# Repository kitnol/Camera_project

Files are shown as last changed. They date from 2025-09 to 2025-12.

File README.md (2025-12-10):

| Supported Targets | ESP32-S3 |
| --- | --- |

# Basic Console Example (`esp_console_repl`)

(See the README.md file in the upper level 'examples' directory for more information about examples.)

This example illustrates the usage of the REPL (Read-Eval-Print Loop) APIs of the [Console Component](https://docs.espressif.com/projects/esp-idf/en/latest/esp32/api-reference/system/console.html#console) to create an interactive shell on the ESP chip. The interactive shell running on the ESP chip can then be controlled/interacted with over a serial interface. This example supports UART and USB interfaces.

The interactive shell implemented in this example contains a wide variety of commands, and can act as a basis for applications that require a command-line interface (CLI).

Compared to the [advanced console example](../advanced), this example requires less code to initialize and run the console. `esp_console_repl` API handles most of the details. If you'd like to customize the way console works (for example, process console commands in an existing task), please check the advanced console example.

## How to use example

This example can be used on boards with UART and USB interfaces. The sections below explain how to set up the board and configure the example.

### Using with UART

When UART interface is used, this example should run on any commonly available Espressif development board. UART interface is enabled by default (`CONFIG_ESP_CONSOLE_UART_DEFAULT` option in menuconfig). No extra configuration is required.

### Using with USB_SERIAL_JTAG

*NOTE: We recommend to disable the secondary console output on chips with USB_SERIAL_JTAG since the secondary serial is output-only and would not be very useful when using a console application. This is why the secondary console output is deactivated per default (CONFIG_ESP_CONSOLE_SECONDARY_NONE=y)*

On chips with USB_SERIAL_JTAG peripheral, console example can be used over the USB serial port.

* First, connect the USB cable to the USB_SERIAL_JTAG interface.
* Second, run `idf.py menuconfig` and enable `CONFIG_ESP_CONSOLE_USB_SERIAL_JTAG` option.

For more details about connecting and configuring USB_SERIAL_JTAG (including pin numbers), see the IDF Programming Guide:
* [ESP32-C3 USB_SERIAL_JTAG](https://docs.espressif.com/projects/esp-idf/en/stable/esp32c3/api-guides/usb-serial-jtag-console.html)
* [ESP32-S3 USB_SERIAL_JTAG](https://docs.espressif.com/projects/esp-idf/en/stable/esp32s3/api-guides/usb-serial-jtag-console.html)

### Using with USB CDC (USB_OTG peripheral)

USB_OTG peripheral can also provide a USB serial port which works with this example.

* First, connect the USB cable to the USB_OTG peripheral interface.
* Second, run `idf.py menuconfig` and enable `CONFIG_ESP_CONSOLE_USB_CDC` option.

For more details about connecting and configuring USB_OTG (including pin numbers), see the IDF Programming Guide:
* [ESP32-S2 USB_OTG](https://docs.espressif.com/projects/esp-idf/en/stable/esp32s2/api-guides/usb-otg-console.html)
* [ESP32-S3 USB_OTG](https://docs.espressif.com/projects/esp-idf/en/stable/esp32s3/api-guides/usb-otg-console.html)

### Other configuration options

This example has an option to store the command history in Flash. This option is enabled by default.

To disable this, run `idf.py menuconfig` and disable `CONFIG_CONSOLE_STORE_HISTORY` option.

### Build and Flash

Build the project and flash it to the board, then run monitor tool to view serial output:

```
idf.py -p PORT flash monitor
```

(Replace PORT with the name of the serial port to use.)

(To exit the serial monitor, type ``Ctrl-]``.)

See the Getting Started Guide for full steps to configure and use ESP-IDF to build projects.

## Example Output

Enter the `help` command get a full list of all available commands. The following is a sample session of the Console Example where a variety of commands provided by the Console Example are used.

On ESP32, GPIO15 may be connected to GND to remove the boot log output.

```
This is an example of ESP-IDF console component.
Type 'help' to get the list of commands.
Use UP/DOWN arrows to navigate through command history.
Press TAB when typing command name to auto-complete.
[esp32]> help
help
  Print the list of registered commands

free
  Get the total size of heap memory available

restart
  Restart the program

deep_sleep  [-t <t>] [--io=<n>] [--io_level=<0|1>]
  Enter deep sleep mode. Two wakeup modes are supported: timer and GPIO. If no
  wakeup option is specified, will sleep indefinitely.
  -t, --time=<t>  Wake up time, ms
      --io=<n>  If specified, wakeup using GPIO with given number
  --io_level=<0|1>  GPIO level to trigger wakeup

join  [--timeout=<t>] <ssid> [<pass>]
  Join WiFi AP as a station
  --timeout=<t>  Connection timeout, ms
        <ssid>  SSID of AP
        <pass>  PSK of AP

[esp32]> free
257200
[esp32]> deep_sleep -t 1000
I (146929) deep_sleep: Enabling timer wakeup, timeout=1000000us
I (619) heap_init: Initializing. RAM available for dynamic allocation:
I (620) heap_init: At 3FFAE2A0 len 00001D60 (7 KiB): DRAM
I (626) heap_init: At 3FFB7EA0 len 00028160 (160 KiB): DRAM
I (645) heap_init: At 3FFE0440 len 00003BC0 (14 KiB): D/IRAM
I (664) heap_init: At 3FFE4350 len 0001BCB0 (111 KiB): D/IRAM
I (684) heap_init: At 40093EA8 len 0000C158 (48 KiB): IRAM

This is an example of ESP-IDF console component.
Type 'help' to get the list of commands.
Use UP/DOWN arrows to navigate through command history.
Press TAB when typing command name to auto-complete.
[esp32]> join --timeout 10000 test_ap test_password
I (182639) connect: Connecting to 'test_ap'
I (184619) connect: Connected
[esp32]> free
212328
[esp32]> restart
I (205639) restart: Restarting
I (616) heap_init: Initializing. RAM available for dynamic allocation:
I (617) heap_init: At 3FFAE2A0 len 00001D60 (7 KiB): DRAM
I (623) heap_init: At 3FFB7EA0 len 00028160 (160 KiB): DRAM
I (642) heap_init: At 3FFE0440 len 00003BC0 (14 KiB): D/IRAM
I (661) heap_init: At 3FFE4350 len 0001BCB0 (111 KiB): D/IRAM
I (681) heap_init: At 40093EA8 len 0000C158 (48 KiB): IRAM

This is an example of ESP-IDF console component.
Type 'help' to get the list of commands.
Use UP/DOWN arrows to navigate through command history.
Press TAB when typing command name to auto-complete.
[esp32]>

```

## Troubleshooting

### Line Endings

The line endings in the Console Example are configured to match particular serial monitors. Therefore, if the following log output appears, consider using a different serial monitor (e.g. Putty for Windows) or modify the example's [UART configuration](#Configuring-UART-and-VFS).

```
This is an example of ESP-IDF console component.
Type 'help' to get the list of commands.
Use UP/DOWN arrows to navigate through command history.
Press TAB when typing command name to auto-complete.
Your terminal application does not support escape sequences.
Line editing and history features are disabled.
On Windows, try using Putty instead.
esp32>
```

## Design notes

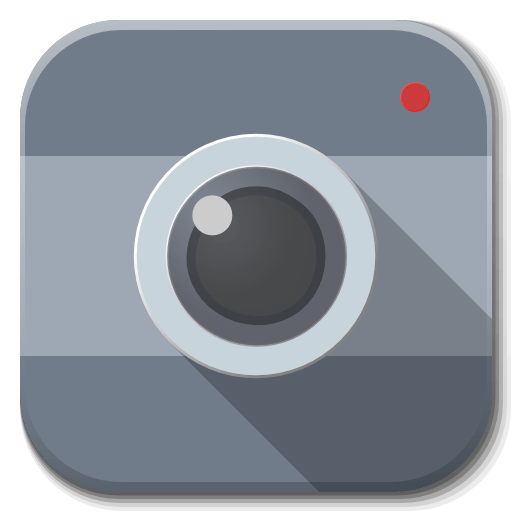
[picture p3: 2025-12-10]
App/Camera.png

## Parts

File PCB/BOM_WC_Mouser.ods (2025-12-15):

Item name/value | Quantity to buy | Link / Order code | Price per unit (gross) | Price
ADPL40502AUJZ-2.8-R7 | 10 | https://www.mouser.dk/ProductDetail/Analog-Devices/ADPL40502AUJZ-2.8-R7?qs=jcD%2FCkGBYeOJfO%252BMa2JGGw%3D%3D | 3.10000 kr. | 31.000 kr.
USB-C Molex 217179-0001 | 10 | https://www.mouser.dk/ProductDetail/Molex/217179-0001?qs=DRkmTr78QAQqCH4BoIR1xg%3D%3D | 4.46000 kr. | 44.600 kr.
ESP32-S3-WROOM-1 N16R8 | 10 | https://www.mouser.dk/ProductDetail/Espressif-Systems/ESP32-S3-WROOM-1-N16R8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 | 39.46000 kr. | 394.600 kr.
AP2111H-3.3TRG1 | 10 | https://www.mouser.dk/ProductDetail/Diodes-Incorporated/AP2111H-3.3TRG1?qs=x6A8l6qLYDCdsdXLicgNOA%3D%3D | 1.97000 kr. | 19.700 kr.
Molex 5033981892 | 5 | https://www.mouser.dk/ProductDetail/Molex/503398-1892?qs=b0v8CoHHvSMxV%252BW12iKaSg%3D%3D | 14.79000 kr. | 73.950 kr.
SW_Push | 10 | https://www.mouser.dk/ProductDetail/CK/KSR231G-LFS?qs=2H7h9CGvDPxeC9NKRK0biQ%3D%3D | 4.08000 kr. | 40.800 kr.
ADPL40502AUJZ-1.5-R7 | 10 | https://www.mouser.dk/ProductDetail/Analog-Devices/ADPL40502AUJZ-1.5-R7?qs=jcD%2FCkGBYeNZFhfla%252BseiA%3D%3D | 3.10000 kr. | 31.000 kr.
D | 10 | https://www.mouser.dk/ProductDetail/Vishay-Semiconductors/VS-10MQ040NTRPBF?qs=CDqwynd4ZNoXSEkPd48Gzg%3D%3D | 2.73000 kr. | 27.300 kr.

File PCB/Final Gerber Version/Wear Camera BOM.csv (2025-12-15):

Id | Designator | Footprint | Quantity | Designation | Supplier and ref
1 | R18,R1,R31,R32,R21,R7,R19,R4,R11,R5,R6,R29,R2,R3 | R_0402_1005Metric | 14 | 10k
2 | R22 | R_0402_1005Metric | 1 | 24.9k
3 | C5,C14,C6,C12,C1,C13 | C_0402_1005Metric | 6 | 100n
4 | C9,C3,C10,C22,C15,C11 | C_0402_1005Metric | 6 | 1u
5 | R10,R9,R14,R30,R8 | R_0402_1005Metric | 5 | 3.3k
6 | U11 | VQFN-16-1EP_3x3mm_P0.5mm_EP1.6x1.6mm | 1 | BQ24074RGT
7 | C4,C7,C8,C23 | C_0402_1005Metric | 4 | 4.7u
8 | R16,R17,R23 | R_0402_1005Metric | 3 | 100k
9 | C27,C26,C28 | C_1210_3225Metric_Pad1.33x2.70mm_HandSolder | 3 | 10u
10 | U3 | SOIC-8_3.9x4.9mm_P1.27mm | 1 | DS3231MZ
11 | R27 | R_0402_1005Metric | 1 | 1.62k
12 | S1,S2 | SW_EVPBB4A9B000 | 2 | C913778
13 | U4 | LGA-14_3x2.5mm_P0.5mm_LayoutBorder3x4y | 1 | LSM6DSM
14 | J2 | OMRON_XF2M-2415-1A | 1 | XF2M-2415-1A BY OMZ
15 | U9 | MOLEX_2171790001 | 1 | Molex 217179-0001
16 | TP1,TP2 | TestPoint_Pad_1.0x1.0mm | 2 | TestPoint_Small
17 | D16 | D_0402_1005Metric | 1 | 16-213SURC/S530-A4/TR8
18 | R26 | R_0402_1005Metric | 1 | 750
19 | D15,D2 | D_0402_1005Metric | 2 | 16-213/BHC-AN1P2/3T
20 | U2 | ESP32-S3-WROOM-1 | 1 | ESP32-S3-WROOM-1
21 | U5 | SOT-23-5 | 1 | LP5907MFX-1.5
22 | U10 | SOT-23-6 | 1 | USBLC6-2SC6
23 | J4 | JST_SH_SM03B-SRSS-TB_1x03-1MP_P1.00mm_Horizontal | 1 | Conn_01x03_Pin
24 | R20 | R_0402_1005Metric | 1 | 20k
25 | C2 | C_0402_1005Metric | 1 | 10u
26 | R25,R24 | R_0805_2012Metric_Pad1.20x1.40mm_HandSolder | 2 | 5.1k
27 | U1 | SOT-223 | 1 | AP2111H-3.3TRG1
28 | R12,R15,R13 | R_0402_1005Metric | 3 | 150R
29 | U6 | SOT-23-5 | 1 | TLV74328PDBVR
30 | BT1 | BAT_3000 | 1 | C238097
31 | R28 | R_0402_1005Metric | 1 | 49.9k
32 | J3 | CONN_503398-1892_MOL | 1 | Molex 5033981892

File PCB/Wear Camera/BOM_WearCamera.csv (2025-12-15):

Id | Designator | Footprint | Quantity | Designation | JLC PCB
1 | C27,C26,C28 | C_1210_3225Metric_Pad1.33x2.70mm_HandSolder | 3 | 10u
2 | R24,R25 | R_0805_2012Metric_Pad1.20x1.40mm_HandSolder | 2 | 5.1k
3 | U9 | MOLEX_2171790001 | 1 | Molex 217179-0001
4 | R17 | R_0402_1005Metric_Pad0.72x0.64mm_HandSolder | 1 | 100k
5 | U3 | SOIC-8_3.9x4.9mm_P1.27mm | 1 | DS3231MZ
6 | C7,C8 | C_0603_1608Metric_Pad1.08x0.95mm_HandSolder | 2 | 4.7u
7 | R18,R11, | R_0402_1005Metric_Pad0.72x0.64mm_HandSolder | 2 | 10k
7 | R21,R19 | R_0402_1005Metric_Pad0.72x0.64mm_HandSolder | 2 | 10k
8 | SW2,SW1 | KSR231GLFS_CNK | 2 | SW_Push
9 | U4 | TSOT-23-5 | 1 | ADPL40502AUJZ-1.5-R7
10 | R23,R16 | R_0603_1608Metric_Pad0.98x0.95mm_HandSolder | 2 | 100k
11 | R12,R15,R13 | R_0402_1005Metric_Pad0.72x0.64mm_HandSolder | 3 | 150R
12 | C1,C5,C6,C12 | C_0402_1005Metric_Pad0.74x0.62mm_HandSolder | 4 | 100n
13 | U2 | ESP32-S3-WROOM-1 | 1 | ESP32-S3-WROOM-1
14 | R9,R8,R10 | R_0603_1608Metric_Pad0.98x0.95mm_HandSolder | 9 | 47k
14 | R4,R2,R6,R5,R3,R29 | R_0603_1608Metric_Pad0.98x0.95mm_HandSolder | 9 | 47k
15 | J1 | JST_PH_S2B-PH-K_1x02_P2.00mm_Horizontal | 1 | Conn_01x02_Pin
16 | C2 | C_0402_1005Metric_Pad0.74x0.62mm_HandSolder | 1 | 10u
17 | J3 | CONN_503398-1892_MOL | 1 | Molex 5033981892
18 | C10,C9,C3,C11, | C_0603_1608Metric_Pad1.08x0.95mm_HandSolder | 4 | 1u
18 | C22 | C_0603_1608Metric_Pad1.08x0.95mm_HandSolder | 1 | 1u
19 | J2 | FFC2B35-24-T | 1 | FFC2B35-24-T
20 | D15, | LED_0603_1608Metric_Pad1.05x0.95mm_HandSolder | 1 | 150060GS55040
20 | D2 | LED_0603_1608Metric_Pad1.05x0.95mm_HandSolder | 1 | 150060GS55040
21 | D16 | LED_0603_1608Metric_Pad1.05x0.95mm_HandSolder | 1 | 150060RS55040
22 | TP3,TP2 | TestPoint_Pad_D1.5mm | 2 | TestPoint_Small
23 | C23,C4 | C_0402_1005Metric_Pad0.74x0.62mm_HandSolder | 2 | 4.7u
24 | R26 | R_0603_1608Metric_Pad0.98x0.95mm_HandSolder | 1 | 750
25 | R1,R7 | R_0805_2012Metric_Pad1.20x1.40mm_HandSolder | 2 | 10k
26 | U5 | TSOT-23-5 | 1 | ADPL40502AUJZ-2.8-R7
27 | U10 | SOT-23-6 | 1 | USBLC6-2SC6
28 | U11 | VQFN-16-1EP_3x3mm_P0.5mm_EP1.6x1.6mm | 1 | BQ24074RGT
29 | BT1 | BatteryHolder_Keystone_3002_1x2032 | 1 | Battery_Cell
30 | U1 | SOT-223 | 1 | AP2111H-3.3TRG1
31 | R22 | R_0603_1608Metric_Pad0.98x0.95mm_HandSolder | 1 | 24.9k
32 | R20 | R_0402_1005Metric_Pad0.72x0.64mm_HandSolder | 1 | 20k
33 | R28 | R_0603_1608Metric_Pad0.98x0.95mm_HandSolder | 1 | 49.9k
34 | D1,D4 | D_SMA | 2 | D
35 | R27 | R_0603_1608Metric_Pad0.98x0.95mm_HandSolder | 1 | 1.62k

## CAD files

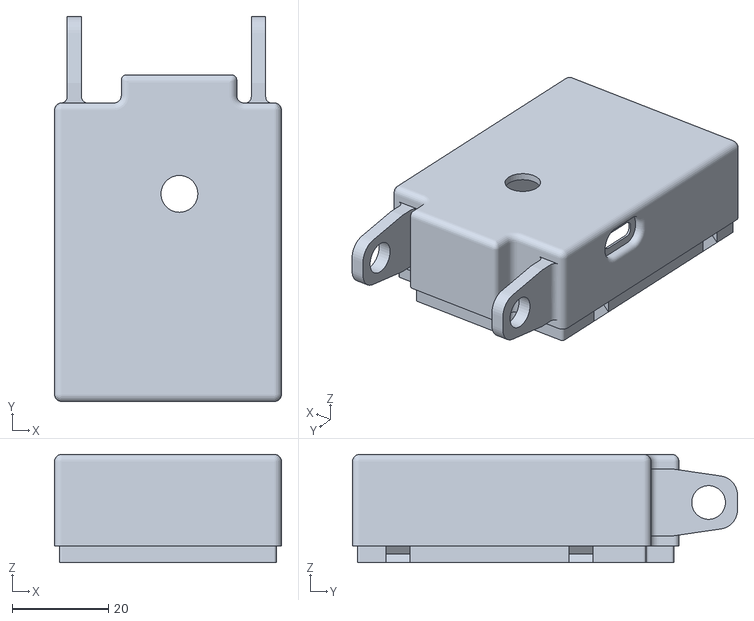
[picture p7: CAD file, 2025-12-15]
3D models/Camera_Main_V6.stl
47.1 x 80.0 x 22.5

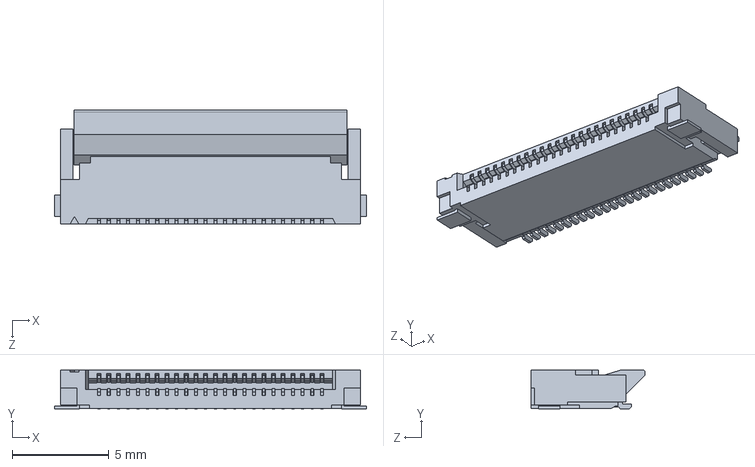
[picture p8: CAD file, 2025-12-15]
PCB/FootPrints/XF2M-2415-1A.STEP
16.1 x 2.00 x 5.90 mm

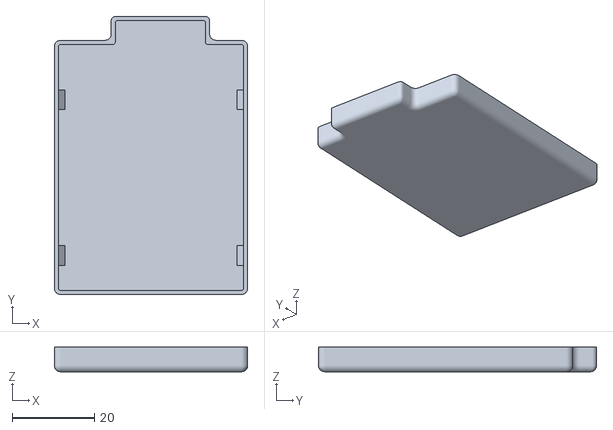
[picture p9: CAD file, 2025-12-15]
3D models/Camera_Back_V6.stl
47.1 x 67.8 x 6.00

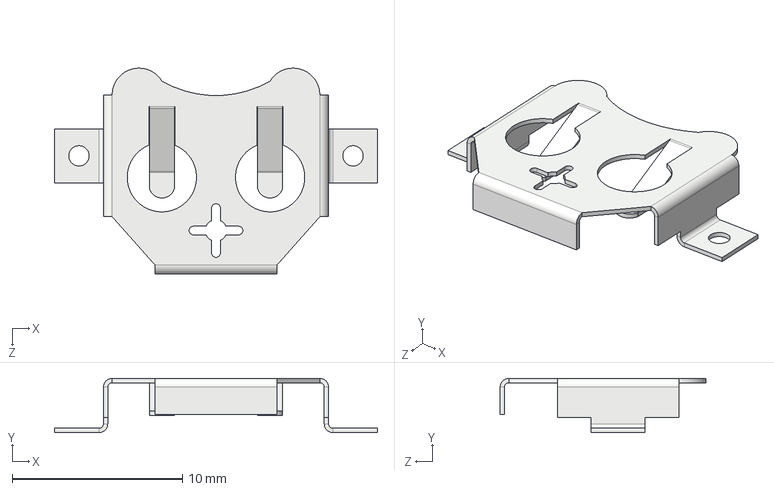
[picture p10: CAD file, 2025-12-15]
PCB/FootPrints/3000.step
18.9 x 3.17 x 12.1 mm

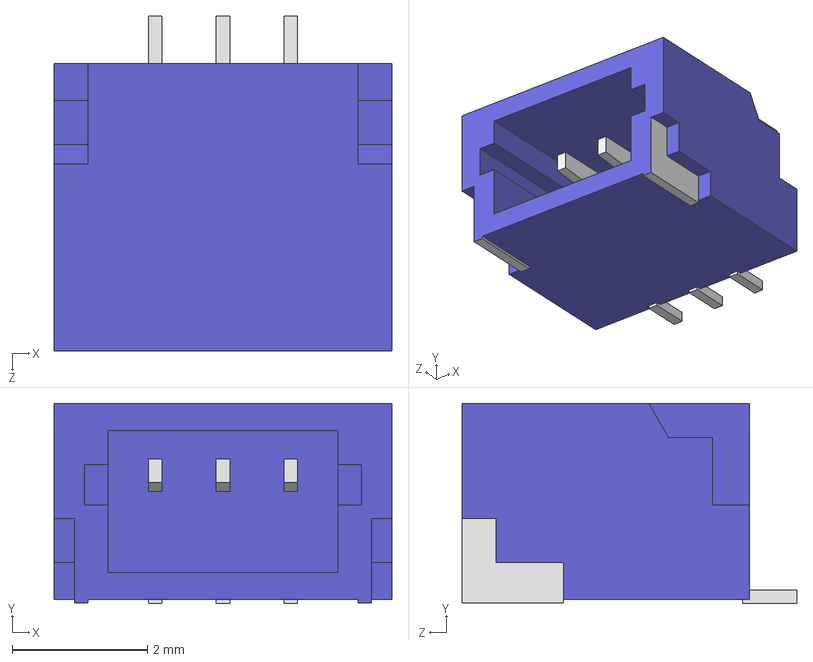
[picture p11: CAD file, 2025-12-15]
PCB/FootPrints/SM03B-SRSS-TB.STEP
5.00 x 2.96 x 4.95 mm

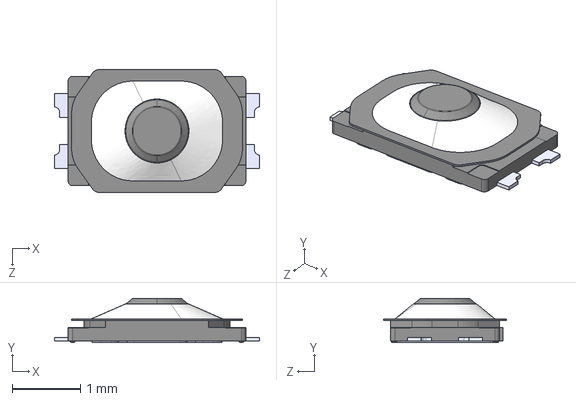
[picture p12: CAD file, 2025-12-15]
PCB/FootPrints/EVPBB4A9B000.step
3.00 x 0.65 x 1.80 mm

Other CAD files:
PCB/Wear Camera/Wear Camera1.gcode.3mf

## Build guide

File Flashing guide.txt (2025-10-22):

Guide on how to flash boards

1. Instaling esptool

Just write

pip install esptool

or

py -m pip install esptool

2. Instaling esp_idf_monitor

pip install esp_idf_monitor

or

py -m pip install esp_idf_monitor

3. You need to make sure that they are in boot mode

By specifics of current firmware on the chips you will need to disamble the casing and take out a board (I will make a video on how to do it)

Then you will need to hold a boot button (it is on a bottom righ from the chip) and while you holding it press reset button (it is on the left top)

Now you are in the boot mode

4. Prepare for uploading

!IMPORTANT!
Unzip archive with binary1 to some folder, there should be following folder structure:

YOUR_FOLDER
|--build
|  |--bootloader
|  |--partition_table

If it not, text me, most likely I messed up somewhere

5. Upload firmware

Fisrt in console navigate to "YOUR_FOLDER" where the build folder is stored

While camera disambeled connect it via USB cable to you computer and input following command

python -m esptool --chip esp32s3 -b 460800 --before default_reset --after hard_reset write_flash --flash_mode dio --flash_size 16MB --flash_freq 80m 0x0 build\bootloader\bootloader.bin 0x8000 build\partition_table\partition-table.bin 0x10000 build\console.bin

It should automitically identify port, especially if you do not have anything else connected
If not add -p "PORT_NAME" after esptool
Port you should be able to find in device maneger or similar (not sure about mac)

6. Post uploading process

Click a reset button (on the top left from the chip) again

7. Setting up camera

Start Serial communication by
py -m esp_idf_monitor

You will get some output and in the end will be
esp32> 

write command "login hello" (without quotes obiosly)
It needed bc, otherwise no comands gonna work

Then run following commands to set currrent time on RTC:

init_rtc
settime 2025 10 16 10 14

settime setting time on RTC options follows as <year> <month> <day> <hour> <minute>
if something not works, write "help" in terminal it will give you posible commands and it usage

Then write following command to check if time setted:

gettime

If everything is correct end monitoring by pressing "Ctrl + ]" or "Cmd + ]"

8. Unzip binary2 to different folder
Folder structure should be same as in step 4

9. Upload second binary follwing command:

python -m esptool --chip esp32s3 -b 460800 --before default_reset --after hard_reset write_flash --flash_mode dio --flash_size 16MB --flash_freq 80m 0x0 build\bootloader\bootloader.bin 0x8000 build\partition_table\partition-table.bin 0x10000 build\console.bin

10. Check if it works

Unplug camera and plug it back wait for 10-30 seconds, camera should apear as FLASH DRIVE and you should be able to open picture
If doing that, if you will have time, please charge them, just plug them to charge, it should be done in less then 2 hours, if you will not have time, just return cameras, and say to ARKadiusz and Casper to charge them

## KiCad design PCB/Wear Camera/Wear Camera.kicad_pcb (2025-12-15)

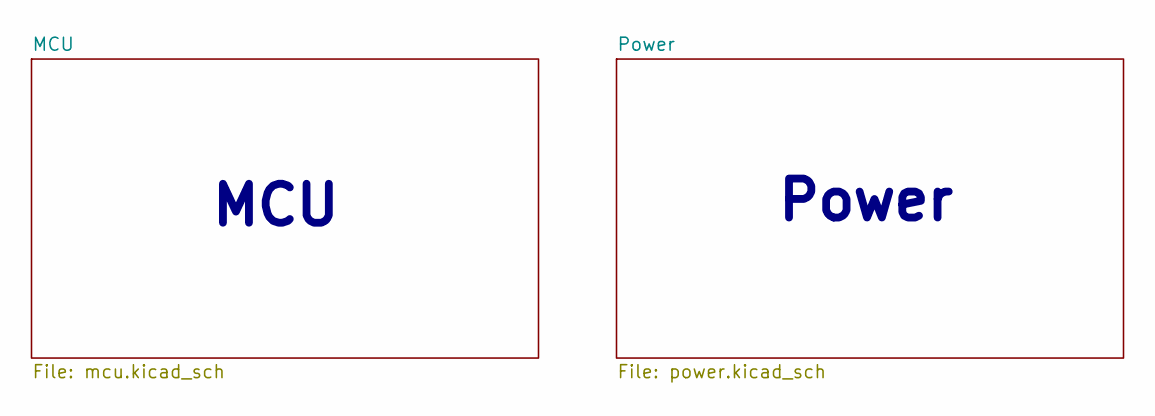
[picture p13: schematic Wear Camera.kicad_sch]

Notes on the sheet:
Power
MCU

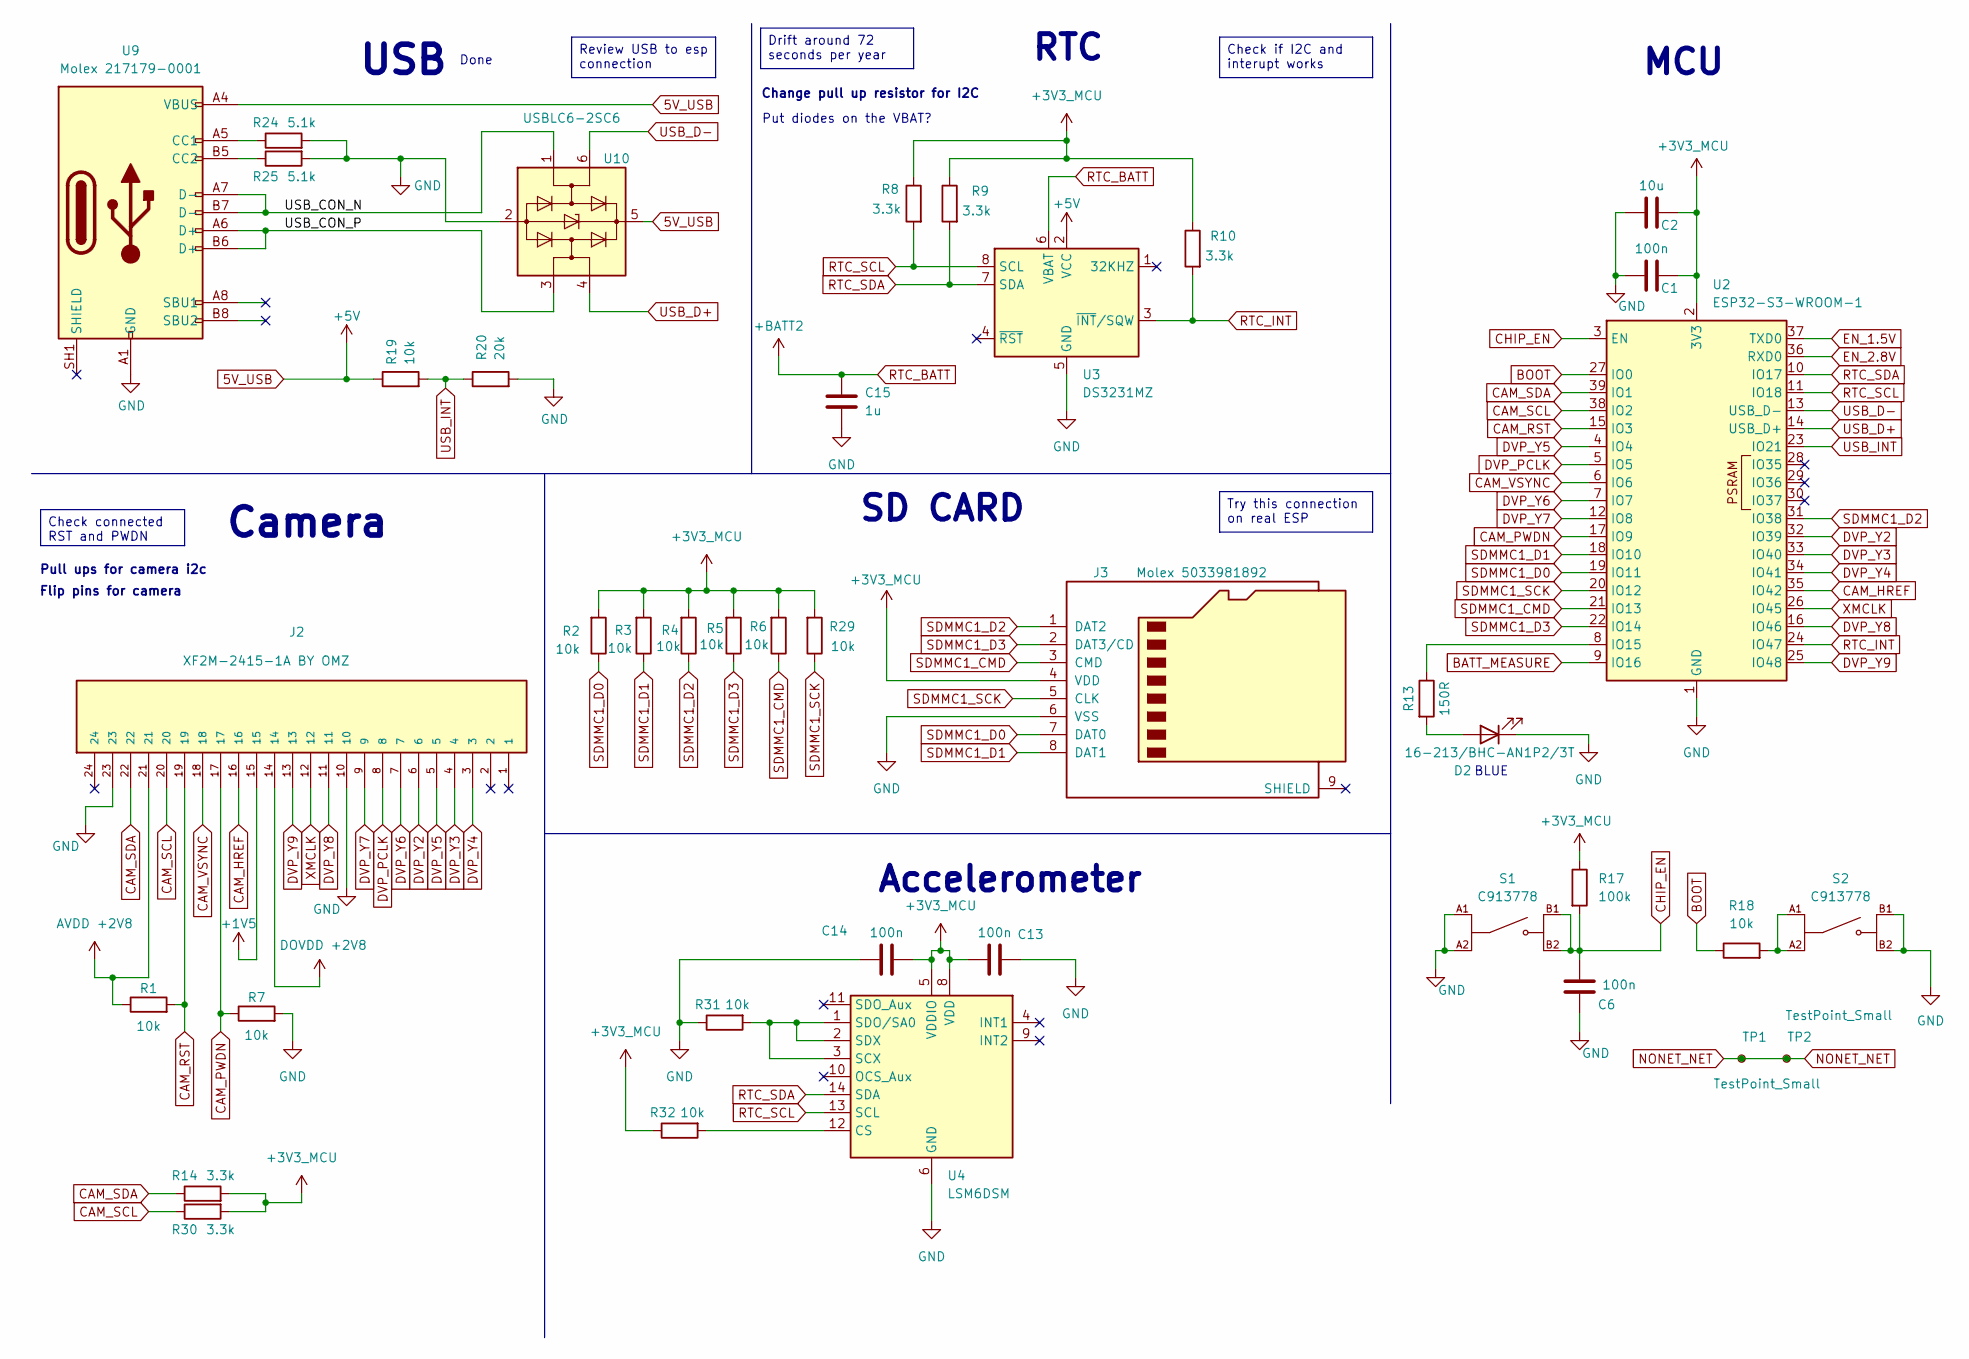
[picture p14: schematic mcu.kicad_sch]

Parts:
C1, C6, C13, C14: 100n; C_0402_1005Metric
C2: 10u; C_0402_1005Metric
C15: 1u; C_0402_1005Metric
D2: 16-213/BHC-AN1P2/3T; D_0402_1005Metric
J2: XF2M-2415-1A BY OMZ; OMRON_XF2M-2415-1A; PARTREV L
J3: Molex 5033981892; CONN_503398-1892_MOL
R1, R2, R3, R4, R5, R6, R7, R18, R19, R29, R31, R32: 10k; R_0402_1005Metric
R8, R9, R10, R14, R30: 3.3k; R_0402_1005Metric
R13: 150R; R_0402_1005Metric
R17: 100k; R_0402_1005Metric
R20: 20k; R_0402_1005Metric
R24, R25: 5.1k; R_0805_2012Metric_Pad1.20x1.40mm_HandSolder
S1, S2: C913778; SW_EVPBB4A9B000; DIGI-KEY_PART_NUMBER P19888CT-ND
TP1, TP2: TestPoint_Small; TestPoint_Pad_1.0x1.0mm
U2: ESP32-S3-WROOM-1
U3: DS3231MZ; SOIC-8_3.9x4.9mm_P1.27mm
U4: LSM6DSM; LGA-14_3x2.5mm_P0.5mm_LayoutBorder3x4y
U9: Molex 217179-0001; MOLEX_2171790001
U10: USBLC6-2SC6; SOT-23-6

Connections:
5V_USB: R19.1, U3.2 (VCC), U9.A4 (VBUS), U9.A9 (VBUS), U10.5 (VBUS); also elsewhere on the board
+1V5: J2.15; also elsewhere on the board
+2V8: J2.14, J2.21, R1.1; also elsewhere on the board
+3V3_MCU: C1.2, C2.2, C13.1, C14.2, J3.4 (VDD), R2.2, R3.2, R4.2, R5.2, R6.2, R8.1, R9.1, R10.1, R14.2, R17.1, R29.2, R30.2, R32.1, U2.2 (3V3), U4.5 (VDDIO), U4.8 (VDD); also elsewhere on the board
/MCU/USB_CON_N: U9.A7 (D-), U9.B7 (D-), U10.1 (I/O1)
/MCU/USB_CON_P: U9.A6 (D+), U9.B6 (D+), U10.3 (I/O2)
BATT_MEASURE: U2.9 (IO16); also elsewhere on the board
BOOT: R18.1, U2.27 (IO0)
CAM_HREF: J2.16, U2.35 (IO42)
CAM_PWDN: J2.17, R7.1, U2.17 (IO9)
CAM_RST: J2.19, R1.2, U2.15 (IO3)
CAM_SCL: J2.20, R30.1, U2.38 (IO2)
CAM_SDA: J2.22, R14.1, U2.39 (IO1)
CAM_VSYNC: J2.18, U2.6 (IO6)
CHIP_EN: C6.2, R17.2, S1.B1, S1.B2, U2.3 (EN)
DVP_PCLK: J2.8, U2.5 (IO5)
DVP_Y2: J2.6, U2.32 (IO39)
DVP_Y3: J2.4, U2.33 (IO40)
DVP_Y4: J2.3, U2.34 (IO41)
DVP_Y5: J2.5, U2.4 (IO4)
DVP_Y6: J2.7, U2.7 (IO7)
DVP_Y7: J2.9, U2.12 (IO8)
DVP_Y8: J2.11, U2.16 (IO46)
DVP_Y9: J2.13, U2.25 (IO48)
EN_1.5V: U2.37 (TXD0); also elsewhere on the board
EN_2.8V: U2.36 (RXD0); also elsewhere on the board
GND: C1.1, C2.1, C6.1, C13.2, C14.1, C15.2, D2.1 (K), J2.10, J2.23, J3.6 (VSS), R7.2, R20.2, R24.2, R25.2, R31.1, S1.A1, S1.A2, S2.B1, S2.B2, U2.1 (GND), U2.40 (GND), U2.41 (GND), U3.5 (GND), U4.6 (GND), U4.7 (GND), U9.A1 (GND), U9.A12 (GND), U10.2 (GND); also elsewhere on the board
NONET_NET: TP1.1, TP2.1
unnamed: D2.2 (A), R13.2
unnamed: R18.2, S2.A1, S2.A2
unnamed: R13.1, U2.8 (IO15)
unnamed: R32.2, U4.12 (CS)
unnamed: R31.2, U4.1 (SDO/SA0), U4.2 (SDX), U4.3 (SCX)
unnamed: R24.1, U9.A5 (CC1)
unnamed: R25.1, U9.B5 (CC2)
RTC_BATT: C15.1, U3.6 (VBAT); also elsewhere on the board
RTC_INT: R10.2, U2.24 (IO47), U3.3 (~INT/SQW)
RTC_SCL: R8.2, U2.11 (IO18), U3.8 (SCL), U4.13 (SCL)
RTC_SDA: R9.2, U2.10 (IO17), U3.7 (SDA), U4.14 (SDA)
SDMMC1_CMD: J3.3 (CMD), R6.1, U2.21 (IO13)
SDMMC1_D0: J3.7 (DAT0), R2.1, U2.19 (IO11)
SDMMC1_D1: J3.8 (DAT1), R3.1, U2.18 (IO10)
SDMMC1_D2: J3.1 (DAT2), R4.1, U2.31 (IO38)
SDMMC1_D3: J3.2 (DAT3/CD), R5.1, U2.22 (IO14)
SDMMC1_SCK: J3.5 (CLK), R29.1, U2.20 (IO12)
USB_D+: U2.14 (USB_D+), U10.4 (I/O2)
USB_D-: U2.13 (USB_D-), U10.6 (I/O1)
USB_INT: R19.2, R20.1, U2.23 (IO21)
XMCLK: J2.12, U2.26 (IO45)

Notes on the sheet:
BLUE
Accelerometer
Done
Change pull up resistor for I2C
Pull ups for camera i2c
SD CARD
MCU
Flip pins for camera
USB
Camera
RTC
Put diodes on the VBAT?
Drift around 72 seconds per year
Try this connection on real ESP
Check if I2C and interupt works
Check connected RST and PWDN
Review USB to esp connection

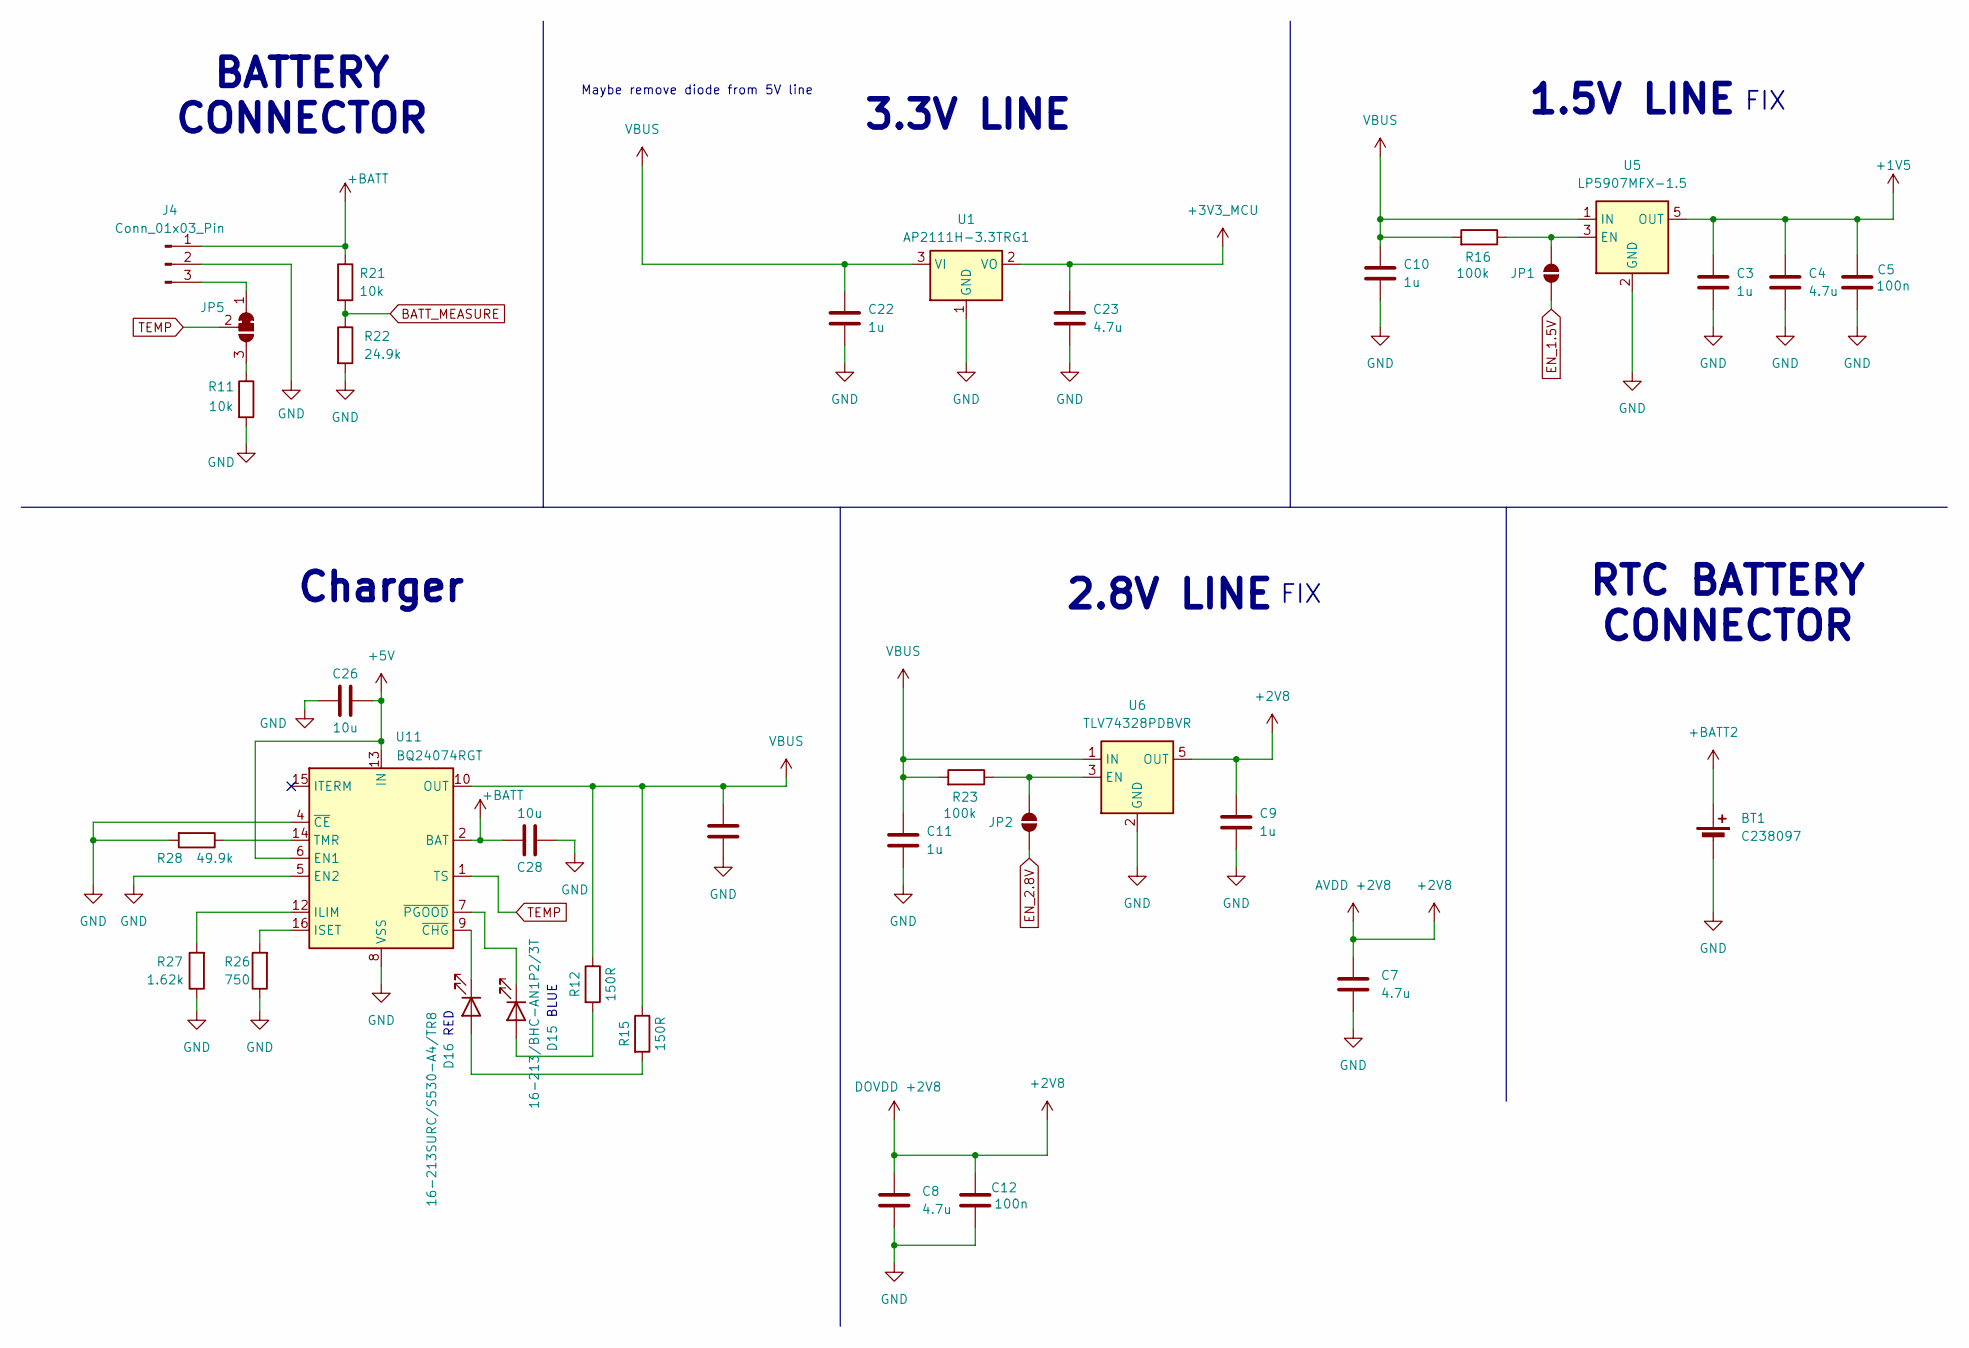
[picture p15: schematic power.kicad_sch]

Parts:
BT1: C238097; BAT_3000
C3, C9, C10, C11, C22: 1u; C_0402_1005Metric
C4, C7, C8, C23: 4.7u; C_0402_1005Metric
C5, C12: 100n; C_0402_1005Metric
C26, C27, C28: 10u; C_1210_3225Metric_Pad1.33x2.70mm_HandSolder
D15: 16-213/BHC-AN1P2/3T; D_0402_1005Metric
D16: 16-213SURC/S530-A4/TR8; D_0402_1005Metric
J4: Conn_01x03_Pin; JST_SH_SM03B-SRSS-TB_1x03-1MP_P1.00mm_Horizontal
JP1, JP2: SolderJumper_2_Open; SolderJumper-2_P1.3mm_Open_RoundedPad1.0x1.5mm
JP5: SolderJumper_3_Bridged12; SolderJumper-3_P1.3mm_Bridged2Bar12_RoundedPad1.0x1.5mm
R11, R21: 10k; R_0402_1005Metric
R12, R15: 150R; R_0402_1005Metric
R16, R23: 100k; R_0402_1005Metric
R22: 24.9k; R_0402_1005Metric
R26: 750; R_0402_1005Metric
R27: 1.62k; R_0402_1005Metric
R28: 49.9k; R_0402_1005Metric
U1: AP2111H-3.3TRG1; SOT-223
U5: LP5907MFX-1.5; SOT-23-5
U6: TLV74328PDBVR; SOT-23-5
U11: BQ24074RGT; VQFN-16-1EP_3x3mm_P0.5mm_EP1.6x1.6mm

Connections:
5V_USB: C26.2, U11.6 (EN1), U11.13 (IN); also elsewhere on the board
+1V5: C3.1, C4.1, C5.2, U5.5 (OUT); also elsewhere on the board
+2V8: C7.1, C8.1, C9.1, C12.2, U6.5 (OUT); also elsewhere on the board
+3V3_MCU: C23.1, U1.2 (VO); also elsewhere on the board
+BATT: C28.1, J4.1, R21.1, U11.2 (BAT), U11.3 (BAT)
BATT_MEASURE: R21.2, R22.1; also elsewhere on the board
EN_1.5V: JP1.1 (A); also elsewhere on the board
EN_2.8V: JP2.1 (A); also elsewhere on the board
GND: BT1.2 (-), C3.2, C4.2, C5.1, C7.2, C8.2, C9.2, C10.2, C11.2, C12.1, C22.2, C23.2, C26.1, C27.2, C28.2, J4.2, R11.2, R22.2, R26.1, R27.1, R28.2, U1.1 (GND), U5.2 (GND), U6.2 (GND), U11.4 (~CE), U11.5 (EN2), U11.8 (VSS), U11.17 (VSS); also elsewhere on the board
unnamed: D15.2 (A), R12.2
unnamed: D15.1 (K), U11.7 (~PGOOD)
unnamed: D16.2 (A), R15.2
unnamed: D16.1 (K), U11.9 (~CHG)
unnamed: J4.3, JP5.1 (A)
unnamed: JP1.2 (B), R16.1, U5.3 (EN)
unnamed: JP2.2 (B), R23.1, U6.3 (EN)
unnamed: JP5.3 (B), R11.1
unnamed: R27.2, U11.12 (ILIM)
unnamed: R26.2, U11.16 (ISET)
unnamed: R28.1, U11.14 (TMR)
RTC_BATT: BT1.1 (+); also elsewhere on the board
TEMP: JP5.2 (C), U11.1 (TS)
VBUS: C10.1, C11.1, C22.1, C27.1, R12.1, R15.1, R16.2, R23.2, U1.3 (VI), U5.1 (IN), U6.1 (IN), U11.10 (OUT), U11.11 (OUT)

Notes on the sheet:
RTC BATTERY CONNECTOR
FIX
2.8V LINE
Charger
Maybe remove diode from 5V line
3.3V LINE
BATTERY CONNECTOR
BLUE
1.5V LINE
RED

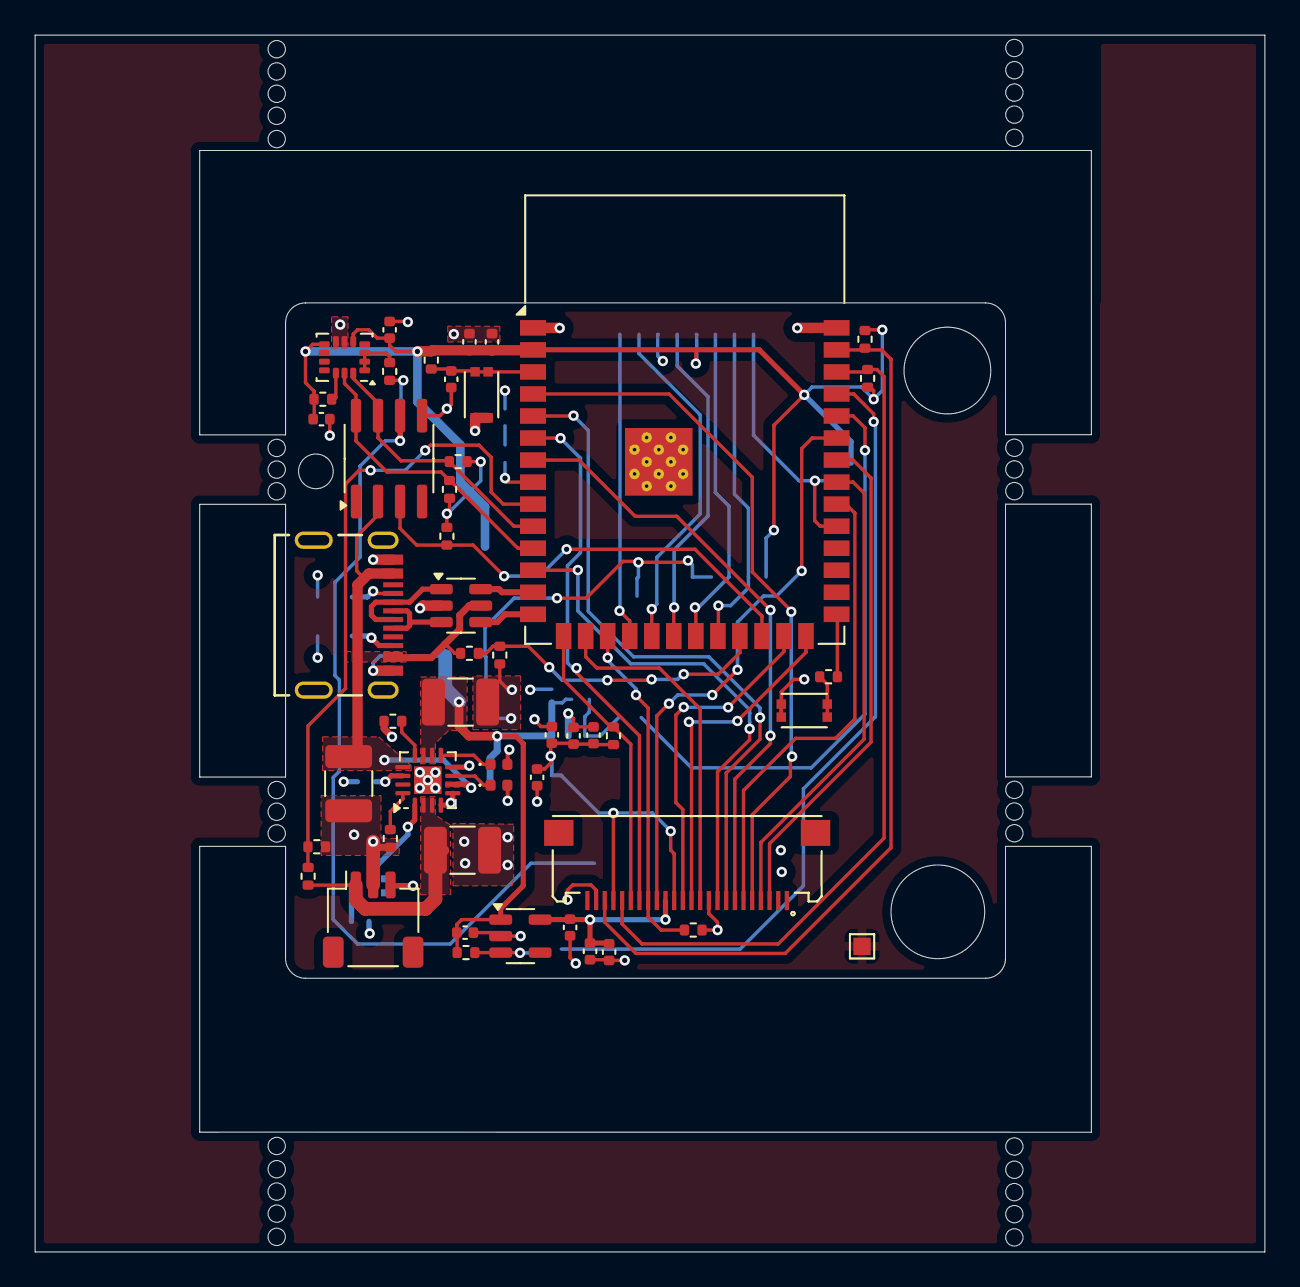
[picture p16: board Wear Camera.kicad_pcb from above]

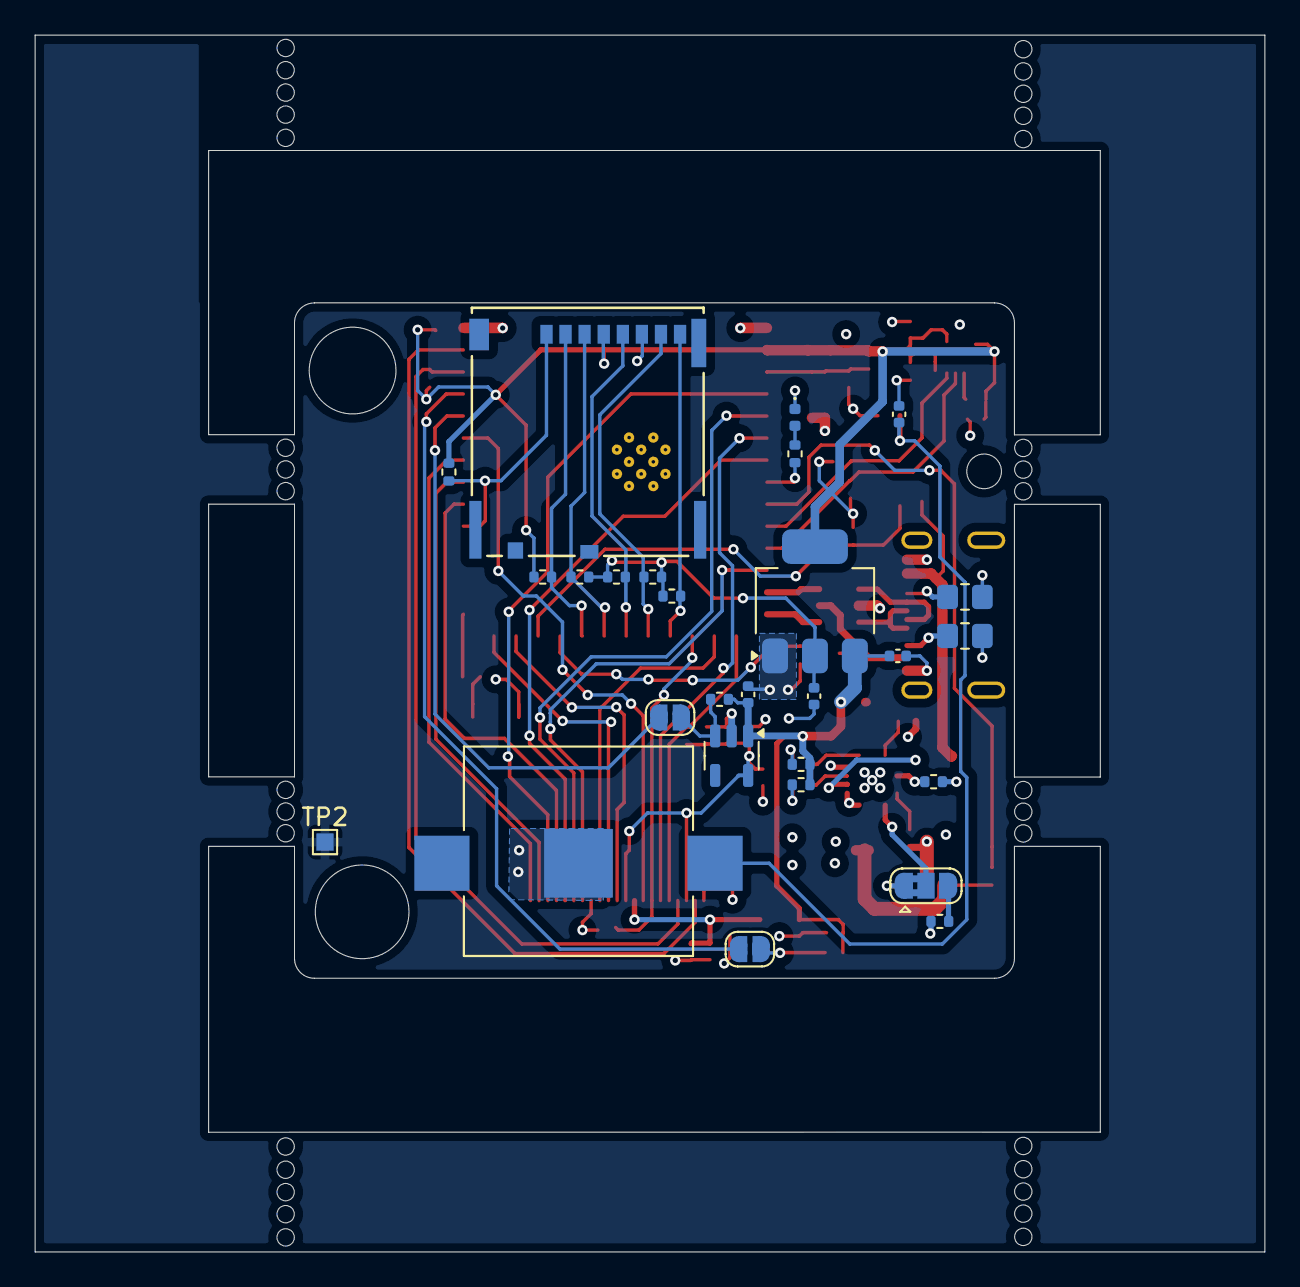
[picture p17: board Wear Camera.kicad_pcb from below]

Board: 4 copper layers, 70.9 x 70.1 mm, 75 parts (27 on the bottom side), 63 nets.

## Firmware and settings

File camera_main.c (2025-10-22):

#include <stdio.h>
#include <stdlib.h>
#include <string.h>
#include <sys/unistd.h>
#include <sys/stat.h>
#include "freertos/FreeRTOS.h"
#include "freertos/task.h"
#include "esp_heap_caps.h"

#include "esp_system.h"
#include "esp_log.h"
#include "esp_console.h"


#include "esp_camera.h"
#include "esp_vfs_dev.h"
#include "esp_vfs_fat.h"
#include "sdmmc_cmd.h"
#include "driver/sdmmc_host.h"

#include "nvs.h"
#include "nvs_flash.h"
#include "cmd_system.h"
#include "cmd_nvs.h"
#include "argtable3/argtable3.h"

#include "driver/i2c_master.h"
#include "driver/i2c.h"
#include "driver/i2c_master.h"
#include "driver/i2c_slave.h"
#include "esp_mac.h"
#include <portmacro.h>

#include "esp_sleep.h"
#include "driver/uart.h"
#include "driver/gpio.h"
#include "hal/gpio_types.h"

#include "esp_partition.h"
#include "tinyusb.h"
#include "tusb_msc_storage.h"
#include "diskio_impl.h"
#include "diskio_sdmmc.h"

#include "ds3231.h"

#include "esp_adc/adc_oneshot.h"
#include "esp_adc/adc_cali.h"
#include "esp_adc/adc_cali_scheme.h"
#include "soc/adc_channel.h"
#include "esp_timer.h"

#define CAM_PIN_PWDN 9  // Power down pin (not used)
#define CAM_PIN_RESET 3 // Reset pin (not used)
#define CAM_PIN_XCLK 45 // External clock (safe pin) +
#define CAM_PIN_SIOD 1  // I2C SDA (safe pin) +
#define CAM_PIN_SIOC 2  // I2C SCL (safe pin) +

#define CAM_PIN_D7 48   // Data 7 (safe pin) +
#define CAM_PIN_D6 46   // Data 6 (safe pin) +
#define CAM_PIN_D5 8    // Data 5 (safe pin) +
#define CAM_PIN_D4 7    // Data 4 (safe pin) +
#define CAM_PIN_D3 4    // Data 3 (safe pin) +
#define CAM_PIN_D2 41   // Data 2 (safe pin) +
#define CAM_PIN_D1 40   // Data 1 (safe pin) +
#define CAM_PIN_D0 39   // Data 0 (safe pin) +
#define CAM_PIN_VSYNC 6 // Vertical sync (safe pin) +
#define CAM_PIN_HREF 42 // Horizontal reference (safe pin)
#define CAM_PIN_PCLK 5  // Pixel clock (safe pin) +

#define CAM_PWR CAM_PIN_PWDN
#define CAM_VREG_28V 

// SD card pin configuration (SDMMC)
#define SD_PIN_SCK 12
#define SD_PIN_CMD 13
#define SD_PIN_D0 11
#define SD_PIN_D1 10
#define SD_PIN_D2 38
#define SD_PIN_D3 14

#define PIN_NUM_MISO SD_PIN_D0  // D0
#define PIN_NUM_MOSI SD_PIN_CMD // CMD
#define PIN_NUM_CLK SD_PIN_SCK  // CLK
#define PIN_NUM_CS SD_PIN_D3    // D3 (not used in 4-line mode but defined)
#define PIN_NUM_D1 SD_PIN_D1    // D1
#define PIN_NUM_D2 SD_PIN_D2    // D2

// SD card pin configuration (SPI mode)
#define PIN_NUM_MISO SD_PIN_D0
#define PIN_NUM_MOSI SD_PIN_CMD
#define PIN_NUM_CLK SD_PIN_SCK
#define PIN_NUM_CS SD_PIN_D3

#define LED_PIN 15
#define USB_INT 21
#define BAT_VOLTAGE 16

#define RTC_SDA 17
#define RTC_SCL 18

#define MOUNT_POINT "/sdcard"
sdmmc_card_t *card_handle;
static bool sd_card_mounted = false;

RTC_DATA_ATTR int running_mode = 0; // 0 = normal, 1 = motion detection
login_state_t login_state = LOGIN_NOT_ATEMPTED;
#define CORRECT_PASSWORD "hello"

typedef enum
{
    SYSTEM_STATE_INIT,
    SYSTEM_STATE_CAPTURE,
    SYSTEM_STATE_SAVE,
    SYSTEM_STATE_CLEANUP,
    SYSTEM_STATE_SLEEP,
    SYSTEM_STATE_USB_CONNECTED,
    SYSTEM_STATE_FLASH_DRIVE
} system_state_t;

typedef enum
{
    LOGIN_NOT_ATEMPTED,
    LOGIN_SUCCESSFUL,
    LOGIN_UNSUCCESSFUL,
    LOGIN_TIME_OUT,
    LOGIN_TO_FLASH_DRIVE
} login_state_t;

/* ----------------------------------- FUNCTIONS --------------------------------------- */

/* Camera functions */
static camera_config_t camera_config = {
    .pin_pwdn = -1,
    .pin_reset = CAM_PIN_RESET,
    .pin_xclk = CAM_PIN_XCLK,
    .pin_sccb_sda = CAM_PIN_SIOD,
    .pin_sccb_scl = CAM_PIN_SIOC,

    .pin_d7 = CAM_PIN_D7,
    .pin_d6 = CAM_PIN_D6,
    .pin_d5 = CAM_PIN_D5,
    .pin_d4 = CAM_PIN_D4,
    .pin_d3 = CAM_PIN_D3,
    .pin_d2 = CAM_PIN_D2,
    .pin_d1 = CAM_PIN_D1,
    .pin_d0 = CAM_PIN_D0,
    .pin_vsync = CAM_PIN_VSYNC,
    .pin_href = CAM_PIN_HREF,
    .pin_pclk = CAM_PIN_PCLK,

    .xclk_freq_hz = 20000000,
    .ledc_timer = LEDC_TIMER_0,
    .ledc_channel = LEDC_CHANNEL_0,

    .pixel_format = PIXFORMAT_JPEG,
    .frame_size = FRAMESIZE_5MP,       // Reduced from UXGA (800x600 instead of 1600x1200)
    .jpeg_quality = 10,                // Lower quality to reduce memory usage
    .fb_count = 2,                     // Single frame buffer without PSRAM
    .fb_location = CAMERA_FB_IN_PSRAM, // Use DRAM instead of PSRAM
    .grab_mode = CAMERA_GRAB_LATEST,
};

esp_err_t init_camera(void)
{

    esp_err_t err = esp_camera_init(&camera_config);
    if (err != ESP_OK)
    {
        ESP_LOGE(TAG, "Camera init failed with error 0x%x", err);
        return err;
    }

    // Get camera sensor
    sensor_t *s = esp_camera_sensor_get();
    if (s == NULL)
    {
        ESP_LOGE(TAG, "Failed to get camera sensor");
        return ESP_FAIL;
    }

    // Configure camera settings for better quality
    s->set_brightness(s, 2);                 // -2 to 2
    s->set_contrast(s, 0);                   // -2 to 2
    s->set_saturation(s, 0);                 // -2 to 2
    s->set_special_effect(s, 0);             // 0 to 6 (0 - No Effect, 1 - Negative, 2 - Grayscale, 3 - Red Tint, 4 - Green Tint, 5 - Blue Tint, 6 - Sepia)
    s->set_whitebal(s, 1);                   // 0 = disable , 1 = enable
    s->set_awb_gain(s, 1);                   // 0 = disable , 1 = enable
    s->set_wb_mode(s, 0);                    // 0 to 4 - if awb_gain enabled (0 - Auto, 1 - Sunny, 2 - Cloudy, 3 - Office, 4 - Home)
    s->set_exposure_ctrl(s, 1);              // 0 = disable , 1 = enable
    s->set_aec2(s, 1);                       // 0 = disable , 1 = enable
    s->set_ae_level(s, 0);                   // -2 to 2
    s->set_aec_value(s, 20);                 // 0 to 1200
    s->set_gain_ctrl(s, 1);                  // 0 = disable , 1 = enable
    s->set_agc_gain(s, 15);                  // 0 to 30
    s->set_gainceiling(s, (gainceiling_t)4); // 0 to 6
    s->set_bpc(s, 1);                        // 0 = disable , 1 = enable
    s->set_wpc(s, 1);                        // 0 = disable , 1 = enable
    s->set_raw_gma(s, 1);                    // 0 = disable , 1 = enable
    s->set_lenc(s, 1);                       // 0 = disable , 1 = enable
    s->set_hmirror(s, 0);                    // 0 = disable , 1 = enable
    s->set_vflip(s, 0);                      // 0 = disable , 1 = enable
    s->set_dcw(s, 1);                        // 0 = disable , 1 = enable
    s->set_colorbar(s, 0);                   // 0 = disable , 1 = enable

    sens = s;

    return ESP_OK;
}

esp_err_t deinit_camera(void)
{
    // Perform sensor software reset before deinitializing
    if (sens != NULL)
    {
        // Try to reset the sensor via I2C (OV5640 specific)
        // This helps ensure clean state for reinitialization
        sens->set_reg(sens, 0x3008, 0xff, 0x82); // Software reset
        vTaskDelay(pdMS_TO_TICKS(10));           // Wait for reset to complete

        // Clear the sensor reference
        sens = NULL;
    }

    // Deinitialize the camera driver
    esp_err_t err = esp_camera_deinit();
    if (err != ESP_OK)
    {
        ESP_LOGE(TAG, "Camera deinit failed with error 0x%x", err);
        return err;
    }

    return ESP_OK;
}

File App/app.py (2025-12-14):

from PyQt5 import QtCore, QtGui, QtWidgets
import serial.tools.list_ports
import serial
import queue
from tkinter import filedialog as fd
from tkinter.messagebox import askyesno, askquestion
import subprocess
import os

import esptool
from esptool.cmds import detect_chip


class DateTimeSelectionDialog(QtWidgets.QDialog):
    """Custom dialog for selecting date and time"""
    
    def __init__(self, parent=None):
        super().__init__(parent)
        self.setWindowTitle("Set Custom Date and Time")
        self.setGeometry(100, 100, 400, 300)
        
        layout = QtWidgets.QVBoxLayout()
        
        # Date selection
        date_layout = QtWidgets.QHBoxLayout()
        date_layout.addWidget(QtWidgets.QLabel("Date:"))
        self.date_edit = QtWidgets.QDateEdit()
        self.date_edit.setDate(QtCore.QDate.currentDate())
        self.date_edit.setCalendarPopup(True)
        date_layout.addWidget(self.date_edit)
        layout.addLayout(date_layout)
        
        # Time selection
        time_layout = QtWidgets.QHBoxLayout()
        time_layout.addWidget(QtWidgets.QLabel("Time:"))
        self.time_edit = QtWidgets.QTimeEdit()
        self.time_edit.setTime(QtCore.QTime.currentTime())
        self.time_edit.setDisplayFormat("HH:mm")
        time_layout.addWidget(self.time_edit)
        layout.addLayout(time_layout)
        
        # Buttons
        button_layout = QtWidgets.QHBoxLayout()
        
        ok_button = QtWidgets.QPushButton("OK")
        ok_button.clicked.connect(self.accept)
        button_layout.addWidget(ok_button)
        
        cancel_button = QtWidgets.QPushButton("Cancel")
        cancel_button.clicked.connect(self.reject)
        button_layout.addWidget(cancel_button)
        
        layout.addLayout(button_layout)
        
        self.setLayout(layout)
    
    def get_selected_datetime(self):
        """Return selected date and time"""
        date = self.date_edit.date()
        time = self.time_edit.time()
        return {
            'year': date.year(),
            'month': date.month(),
            'day': date.day(),
            'hour': time.hour(),
            'minute': time.minute()
        }

PORT = "COM13"  # Change to your port
FLASH_ADDRESS = 0x10000
folder_path = ""

def progress_callback(percent):
    print(f"Wrote: {int(percent)}%")

def flash_esp_firmware(port, bin_file, flash_address=0x0, progress_callback=None):
    """
    Flash firmware to an ESP microcontroller.
    
    Args:
        port: Serial port where ESP is connected (e.g., 'COM3' or '/dev/ttyUSB0')
        bin_file: Path to the binary firmware file
        flash_address: Starting address in flash memory (default: 0x0)
        progress_callback: Optional callback function for progress updates (receives percentage 0-100)
    
    Returns:
        dict: Information about the flashing operation including chip description and success status
    """
    try:
        with detect_chip(port) as esp:
            # Detect chip and get info
            description = esp.get_chip_description()
            features = esp.get_chip_features()
            print(f"Detected ESP on port {port}: {description}")
            print("Features:", ", ".join(features))

            # Load stub for faster flashing
            esp = esp.run_stub()
            
            with open(bin_file, 'rb') as binary:
                # Load the binary
                binary_data = binary.read()
                total_size = len(binary_data)
                print(f"Binary size: {total_size} bytes")

                # Write binary blocks
                esp.flash_begin(total_size, flash_address)
                for i in range(0, total_size, esp.FLASH_WRITE_SIZE):
                    block = binary_data[i:i + esp.FLASH_WRITE_SIZE]
                    # Pad the last block
                    block = block + bytes([0xFF]) * (esp.FLASH_WRITE_SIZE - len(block))
                    esp.flash_block(block, i + flash_address)
                    
                    # Call progress callback if provided
                    if progress_callback:
                        progress_callback(i / total_size * 100)
                
                esp.flash_finish()

                # Reset the chip out of bootloader mode
                esp.hard_reset()
                
                # Final progress update
                if progress_callback:
                    progress_callback(100)
                
                return {
                    'success': True,
                    'chip': description,
                    'features': features,
                    'size': total_size
                }
    
    except Exception as e:
        print(f"Error flashing firmware: {e}")
        return {
            'success': False,
            'error': str(e)
        }

class SerialReaderThread(QtCore.QThread):
    """Thread to read serial data without blocking GUI"""
    line_received = QtCore.pyqtSignal(str)
    
    def __init__(self, serial_port):
        super().__init__()
        self.serial_port = serial_port
        self.running = True
        self.line_buffer = ""
        
    def run(self):
        """Read lines from serial in background thread"""
        while self.running:
            try:
                if self.serial_port.in_waiting > 0:
                    # Read available bytes
                    data = self.serial_port.read(self.serial_port.in_waiting)
                    chunk = data.decode('utf-8', errors='ignore')
                    self.line_buffer += chunk
                    
                    # Process complete lines
                    while '\n' in self.line_buffer:
                        line, self.line_buffer = self.line_buffer.split('\n', 1)
                        line = line.rstrip('\r')
                        
                        if line:
                            self.line_received.emit(line)
                else:
                    # Small delay to prevent busy waiting
                    QtCore.QThread.msleep(10)
                    
            except Exception as e:
                print(f"Error in serial reader: {e}")
                break
    
    def stop(self):
        """Stop the thread"""
        self.running = False
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

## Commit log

2025-09-03 Console app
    [partitions_example.csv]
2025-09-09 Fixed cam_hal.c recursion issue
    [cam_hal.c, console_example_main.c]
2025-10-22 less power consumption
2025-10-22 Fixed issue with unabling to save a picture after poweroff
    [camera_main.c, console_example_main.c]
2025-10-23 Clearing and oprimising for less power
2025-10-26 Decreased to 11mAh
2025-10-29 Dual core processign of sd card, 10.5mA
2025-11-16 logs printing
2025-12-12 GUI update - ability to update soft on cameras
2025-12-14 Time seetting button
2025-12-15 Images fixes, PCB, 3D models
    [3000.step, BOM_WC_Mouser.ods, BOM_WearCamera.csv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]
